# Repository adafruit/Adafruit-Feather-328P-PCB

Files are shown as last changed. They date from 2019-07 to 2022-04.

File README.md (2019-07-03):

## Adafruit Feather 328P PCB

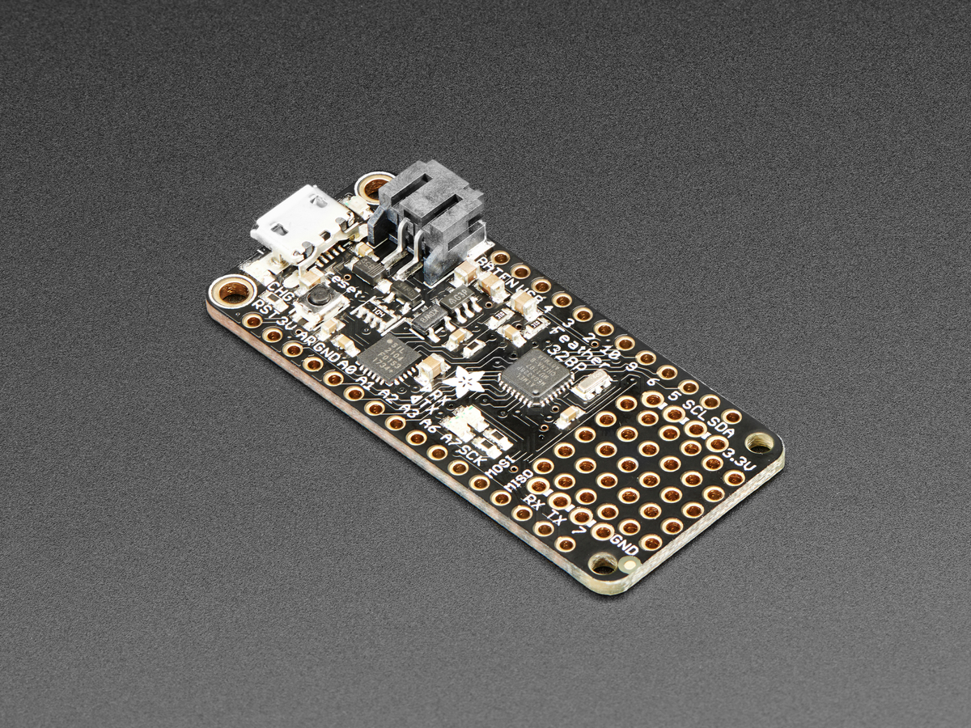
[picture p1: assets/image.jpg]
<a href="http://www.adafruit.com/products/3458"><br/>
Click here to purchase one from the Adafruit shop</a>

PCB files for the Adafruit Feather 328P. Format is EagleCAD schematic and board layout

For more details, check out the product page at
* https://www.adafruit.com/product/3458

### Description

With this Feather we're getting a little nostalgic for the ATmega328P - the classic 'Arduino' chip - with this Adafruit Feather 328P running a 3.3V and 8 MHz. Feather is the new development board from Adafruit, and like it's namesake it is thin, light, and lets you fly! We designed Feather to be a new standard for portable microcontroller cores. We have other boards in the Feather family, check'em out here.

At the Feather 328P's heart is an ATmega328P clocked at 8 MHz and at 3.3V logic, a chip setup we've had tons of experience with as it's the same as the Pro Mini and similar to the Adafruit Metro 328. This chip has 32K of flash and 2K of RAM, and we paired it with a SiLabs CP2104 to give it USB-to-Serial program & debug capability built in. Works great when you want to keep your classic Arduino code compatibility, but want to use one of our dozens of FeatherWings

To make it easy to use for portable projects, we added a connector for any of our 3.7V Lithium polymer batteries and built in battery charging. You don't need a battery, it will run just fine straight from the micro USB connector. But, if you do have a battery, you can take it on the go, then plug in the USB to recharge. The Feather will automatically switch over to USB power when its available. We also tied the battery thru a divider to an analog pin, so you can measure and monitor the battery voltage to detect when you need a recharge.

### License

Adafruit invests time and resources providing this open source design, please support Adafruit and open-source hardware by purchasing products from [Adafruit](https://www.adafruit.com)!

Designed by Limor Fried/Ladyada for Adafruit Industries.

Creative Commons Attribution/Share-Alike, all text above must be included in any redistribution. See license.txt for additional details.

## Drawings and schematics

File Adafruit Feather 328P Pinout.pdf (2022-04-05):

# Adafruit Feather 328P

# https://www.adafruit.com/product/3458 USB RST AR3V A1A0 SCK MOSI BAT GND

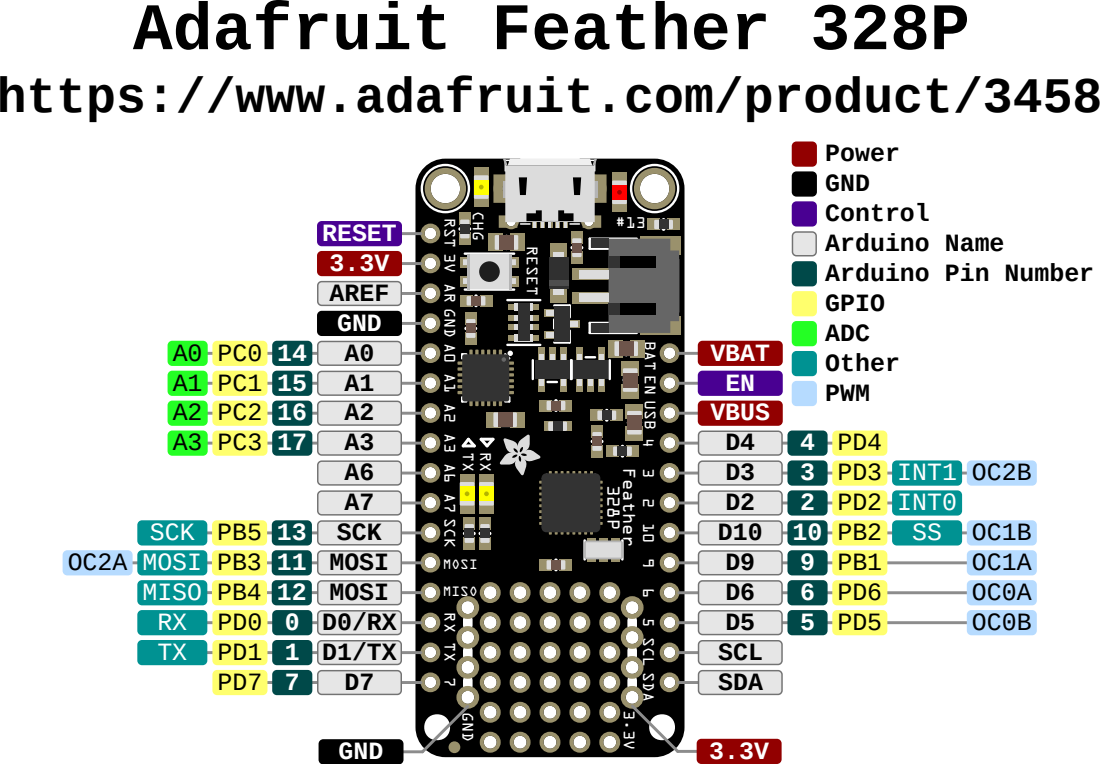
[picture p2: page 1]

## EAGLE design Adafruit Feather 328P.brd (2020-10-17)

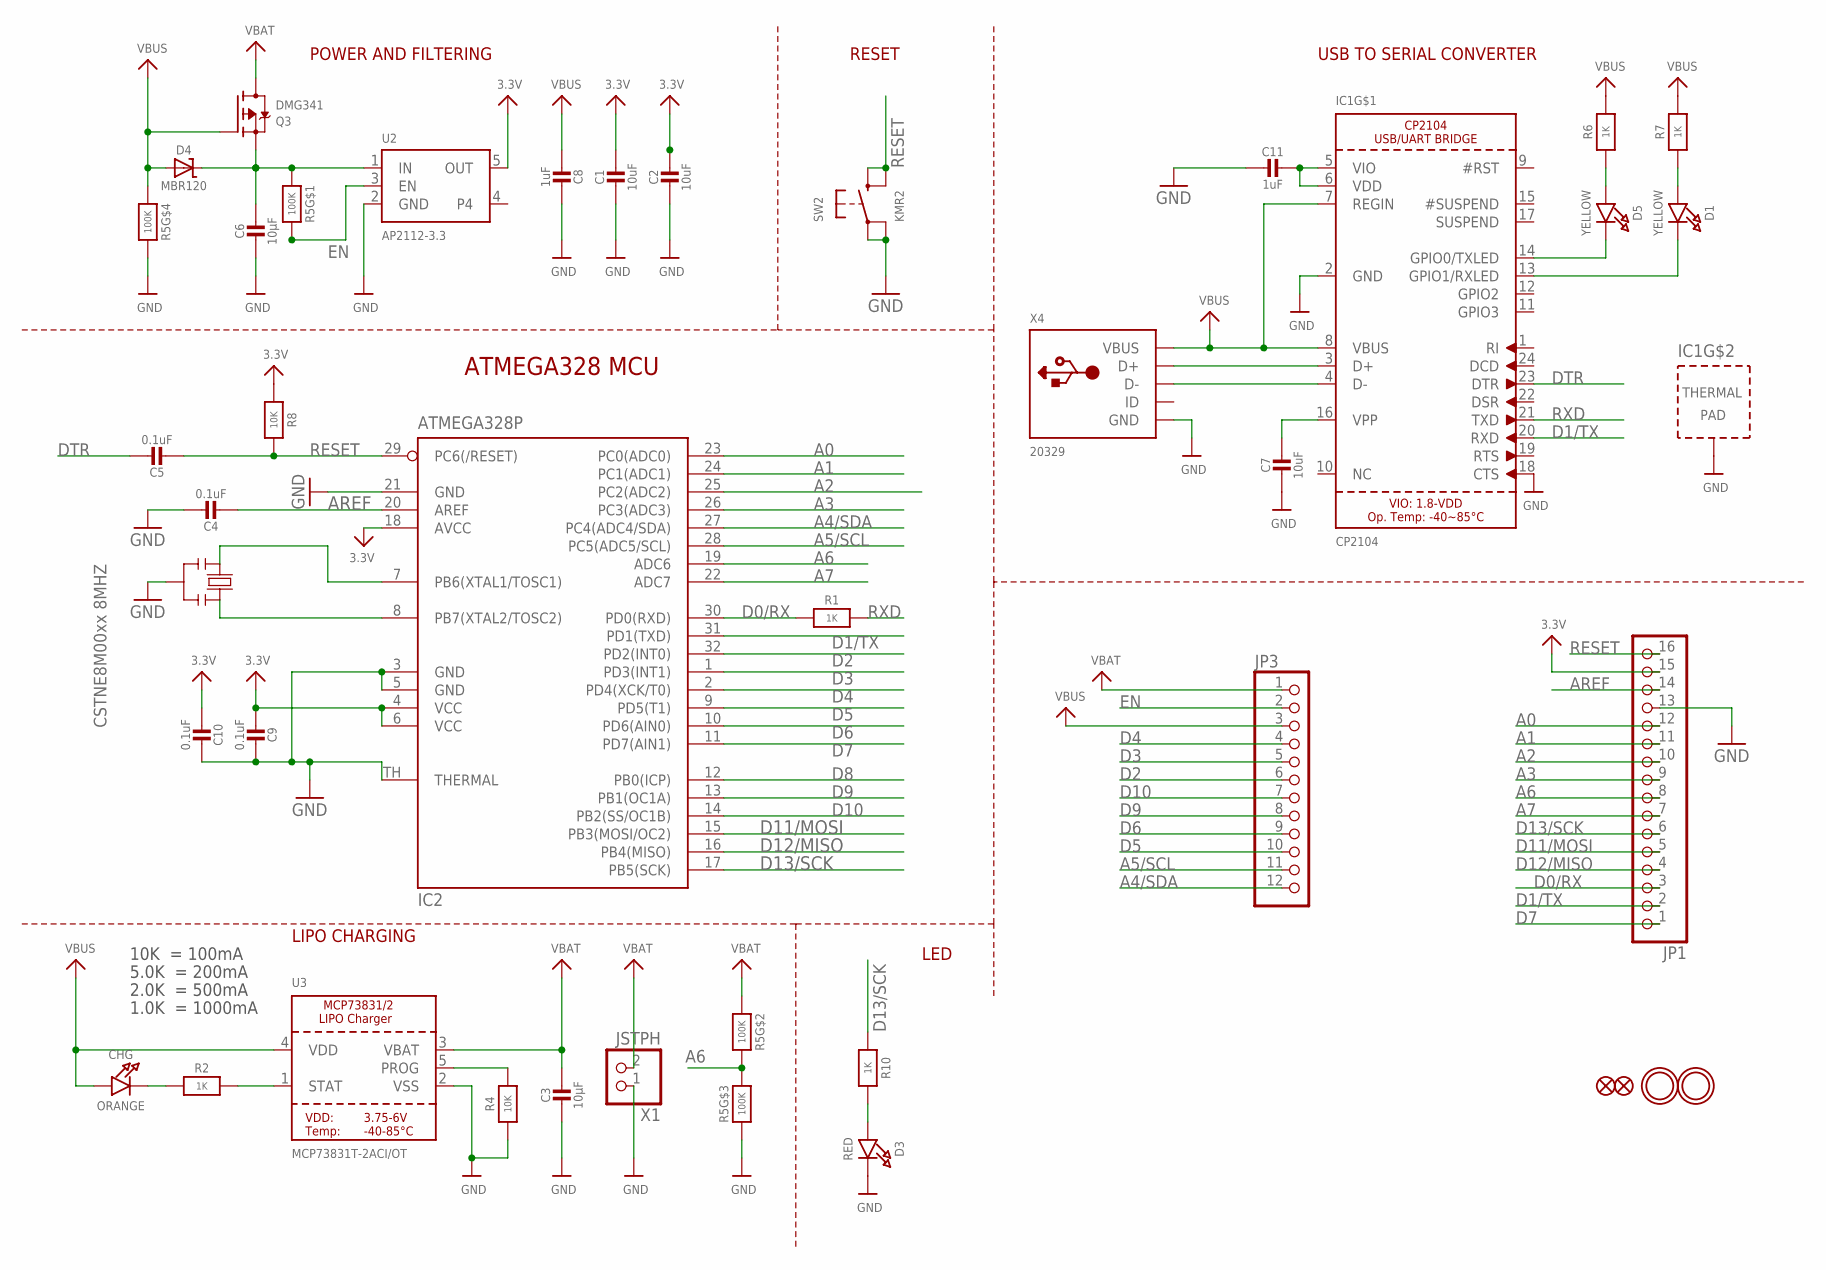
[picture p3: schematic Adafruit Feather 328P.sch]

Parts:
C1, C2: 10uF; 0805-NO
C3, C6: 10µF; 0805-NO
C4, C5, C9, C10: 0.1uF; 0603-NO
C7: 10uF; _0805MP
C8, C11: 1uF; 0603-NO
CHG: ORANGE; CHIPLED_0805_NOOUTLINE
D1, D5: YELLOW; CHIPLED_0805_NOOUTLINE
D3: RED; CHIPLED_0805_NOOUTLINE
D4: MBR120; SOD-123
IC1: CP2104; QFN24_4MM_SMSC
IC2: ATMEGA328P; MLF32-TH
JP1: HEADER-1X16ROUND; 1X16_ROUND
JP3: HEADER-1X12; 1X12_ROUND
Q3: DMG341; SOT23-R
R1: 1K; _0603MP
R2, R6, R7, R10: 1K; 0603-NO
R4, R8: 10K; 0603-NO
R5: 100K; RESPACK_4X0603
SW2: KMR2; BTN_KMR2_4.6X2.8
U2: AP2112-3.3; SOT23-5
U3: MCP73831T-2ACI/OT; SOT23-5
U$31, U$32: MOUNTINGHOLE2.5; MOUNTINGHOLE_2.5_PLATED
U$34, U$35: FIDUCIAL_1MM
X1: JSTPH; JSTPH2
X4: 20329; 4UCONN_20329_V2
Y2: CSTNE8M00xx 8MHZ; RESONATOR

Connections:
3.3V: C1.1, C2.1, C9.2, C10.2, IC2.4 (VCC), IC2.6 (VCC), IC2.18 (AVCC), JP1.15, R8.2, U2.5 (OUT)
A0: IC2.23 (PC0(ADC0)), JP1.12
A1: IC2.24 (PC1(ADC1)), JP1.11
A2: IC2.25 (PC2(ADC2)), JP1.10
A3: IC2.26 (PC3(ADC3)), JP1.9
A4/SDA: IC2.27 (PC4(ADC4/SDA)), JP3.12
A5/SCL: IC2.28 (PC5(ADC5/SCL)), JP3.11
A6: IC2.19 (ADC6), JP1.8, R5.6 (2), R5.7 (2)
A7: IC2.22 (ADC7), JP1.7
AREF: C4.2, IC2.20 (AREF), JP1.14
D0/RX: IC2.30 (PD0(RXD)), JP1.3, R1.1
D1/TX: IC1.20 (RXD), IC2.31 (PD1(TXD)), JP1.2
D2: IC2.32 (PD2(INT0)), JP3.6
D3: IC2.1 (PD3(INT1)), JP3.5
D4: IC2.2 (PD4(XCK/T0)), JP3.4
D5: IC2.9 (PD5(T1)), JP3.10
D6: IC2.10 (PD6(AIN0)), JP3.9
D7: IC2.11 (PD7(AIN1)), JP1.1
D8: IC2.12 (PB0(ICP))
D9: IC2.13 (PB1(OC1A)), JP3.8
D10: IC2.14 (PB2(SS/OC1B)), JP3.7
D11/MOSI: IC2.15 (PB3(MOSI/OC2)), JP1.5
D12/MISO: IC2.16 (PB4(MISO)), JP1.4
D13/SCK: IC2.17 (PB5(SCK)), JP1.6, R10.1
DTR: C5.1, IC1.23 (DTR)
EN: JP3.2, R5.8 (2), U2.3 (EN)
GND: C1.2, C2.2, C3.2, C4.1, C6.2, C7.2, C8.1, C9.1, C10.1, C11.2, D3.C, IC1.2 (GND), IC1.18 (CTS), IC1.THERM (TP), IC2.3 (GND), IC2.5 (GND), IC2.21 (GND), IC2.TH (THERMAL), JP1.13, R4.1, R5.3 (1), R5.5 (2), SW2.A, SW2.A' (P1), U2.2 (GND), U3.2 (VSS), X1.1, X4.BASE@1 (GND), X4.BASE@2 (GND), X4.GND, X4.SPRT@1 (GND), X4.SPRT@2 (GND), X4.SPRT@3 (GND), X4.SPRT@4 (GND), Y2.2
unnamed: CHG.C, R2.1
unnamed: IC1.3 (D+), X4.D+
unnamed: R2.2, U3.1 (STAT)
unnamed: R4.2, U3.5 (PROG)
unnamed: D3.A, R10.2
unnamed: IC1.4 (D-), X4.D-
unnamed: C6.1, D4.C, Q3.2 (S), R5.1, U2.1 (IN)
unnamed: D1.A, R7.1
unnamed: D5.A, R6.1
unnamed: C11.1, IC1.5 (VIO), IC1.6 (VDD)
unnamed: C7.1, IC1.16 (VPP)
RESET: C5.2, IC2.29 (PC6(/RESET)), JP1.16, R8.1, SW2.B (S), SW2.B' (S1)
RXD: IC1.21 (TXD), R1.2
RXLED: D1.C, IC1.13 (GPIO1/RXLED)
TXLED: D5.C, IC1.14 (GPIO0/TXLED)
VBAT: C3.1, JP3.1, Q3.3 (D), R5.2 (1), U3.3 (VBAT), X1.2
VBUS: C8.2, CHG.A, D4.A, IC1.7 (REGIN), IC1.8 (VBUS), JP3.3, Q3.1 (G), R5.4 (1), R6.2, R7.2, U3.4 (VDD), X4.VBUS
XTAL1: IC2.8 (PB7(XTAL2/TOSC2)), Y2.3
XTAL2: IC2.7 (PB6(XTAL1/TOSC1)), Y2.1

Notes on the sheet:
POWER AND FILTERING
RESET
10K = 100mA
5.0K = 200mA
2.0K = 500mA
1.0K = 1000mA
USB TO SERIAL CONVERTER
LIPO CHARGING
LED
ATMEGA328 MCU

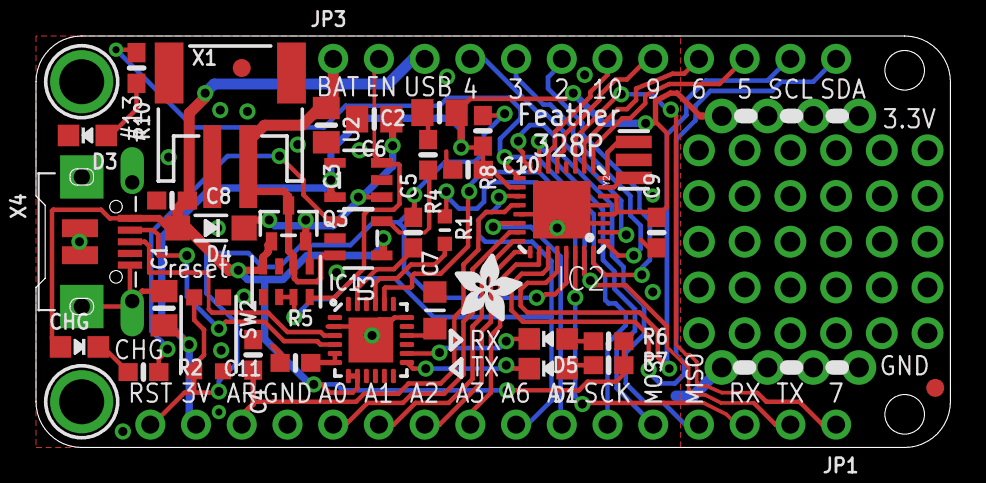
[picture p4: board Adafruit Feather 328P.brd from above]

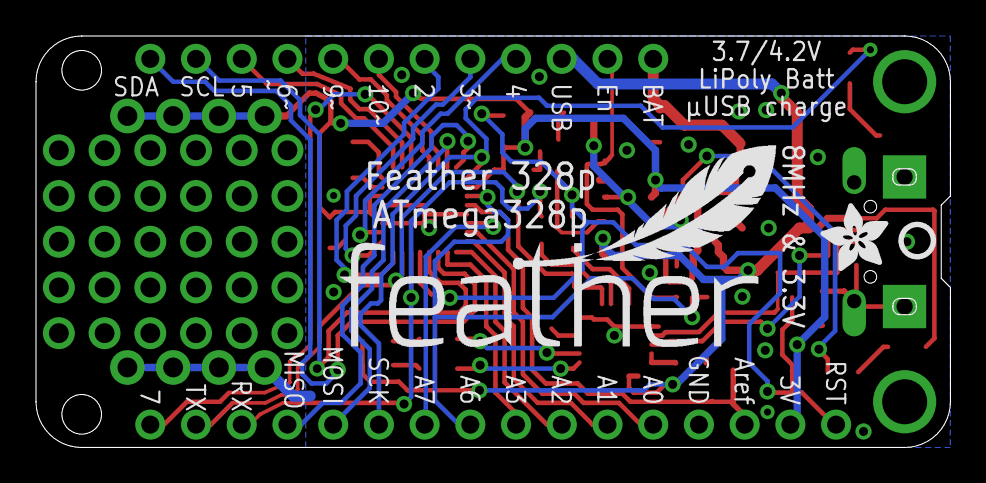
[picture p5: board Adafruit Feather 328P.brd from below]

Board: 2 copper layers, 50.8 x 22.9 mm, 43 parts (3 on the bottom side), 45 nets.

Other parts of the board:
U$9: FEATHERLOGO
U$13: PCBFEAT-REV-040
U$15, U$44: ADAFRUIT_3.5MM

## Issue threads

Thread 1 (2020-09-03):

PWM out of spec?

bergstar, 2020-09-03:
Voltage on PWM signal on this board is below 0.5V - tested on D3. I was only able to trigger around 0.3V. On all other 328P boards I have (other then Adafruit) - both clone and original its close to 5V - I triggered around 4.4V

I can't find anywhere in datasheet that signal below 1.8V could be acceptable for ATmega328P

ladyada, 2020-09-03:
hi for tech support please post in the forums!

Closed 2020-09-03.

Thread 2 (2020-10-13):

wrong resonator

CCommander, 2020-10-13:
Dear Adafruit Team,

The resonator in the schematic states 8 MHz as a value, but the part number refers to a 16 MHz device.

CCommander, 2020-10-18:
Thank you! This helps me to see that my understanding was correct.

Closed 2020-10-17.

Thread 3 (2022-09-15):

Possible issue with spacing of mounting holes

degroof, 2022-09-15:
It looks like the non-plated mounting holes (on the non-USB end of the board) are 0.75" apart instead of 0.7".

The .brd file shows that these holes are 19.1mm apart (0.75"), and 2.2mm in diameter (0.087").
The plated holes are 17.78mm (0.7") apart, and 2.54mm (0.1") in diameter.

Shouldn't these mounting holes be the same size and spacing?

**Non-plated holes**
<hole x="48.26" y="1.8415" drill="2.2"/>
<hole x="48.26" y="20.955" drill="2.2"/>

**Plated Holes**
<element name="U$31" library="microbuilder" package="MOUNTINGHOLE_2.5_PLATED" value="MOUNTINGHOLE2.5" x="2.54" y="20.32" smashed="yes" rot="R270">
<element name="U$32" library="microbuilder" package="MOUNTINGHOLE_2.5_PLATED" value="MOUNTINGHOLE2.5" x="2.54" y="2.54" smashed="yes" rot="R270">

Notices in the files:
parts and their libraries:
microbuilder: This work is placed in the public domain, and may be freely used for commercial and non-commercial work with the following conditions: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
